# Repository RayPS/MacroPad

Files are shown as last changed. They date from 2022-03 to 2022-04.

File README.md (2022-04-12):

<h3 align="center">⌘</h3>
<h1 align="center">MacroPad</h1>
<p align="center">Yet another MacroPad but remotely configurable/scriptable/executable over Wi-Fi.<br>Most importantly, it uses much cheaper solutions than the other existing ones.</p>
<h4 align="center">🚧</h4>

# Hardware

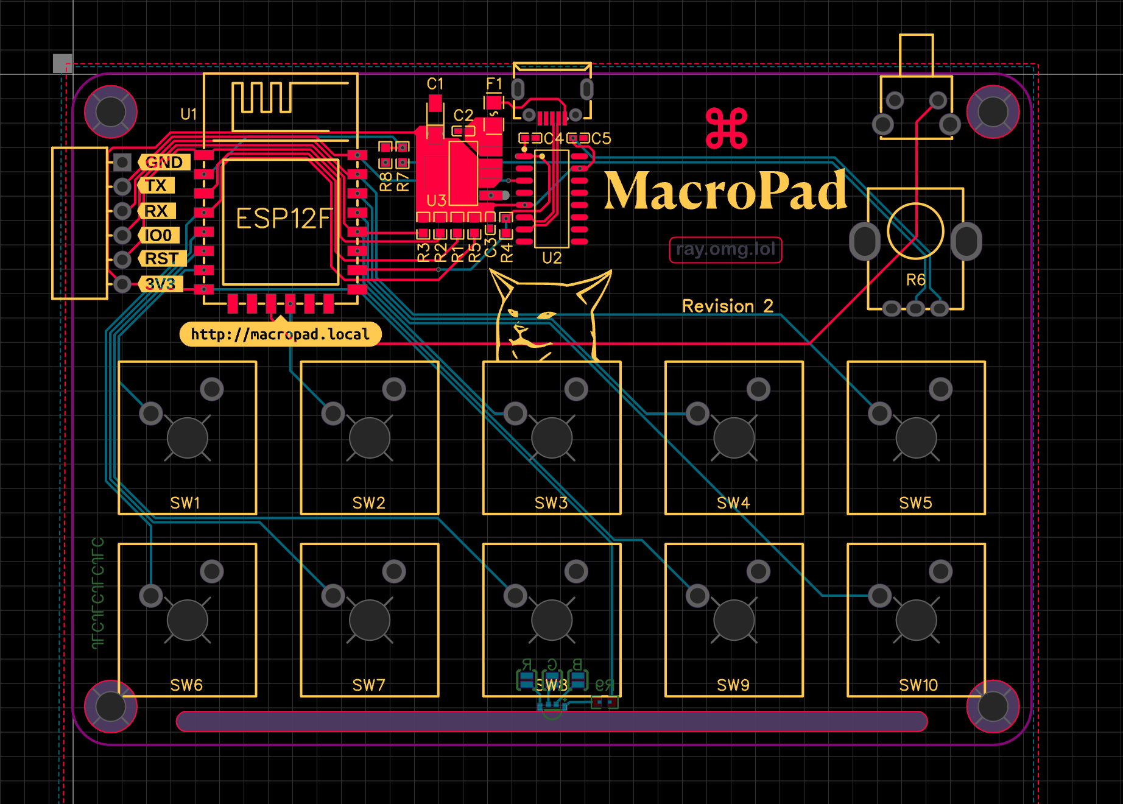
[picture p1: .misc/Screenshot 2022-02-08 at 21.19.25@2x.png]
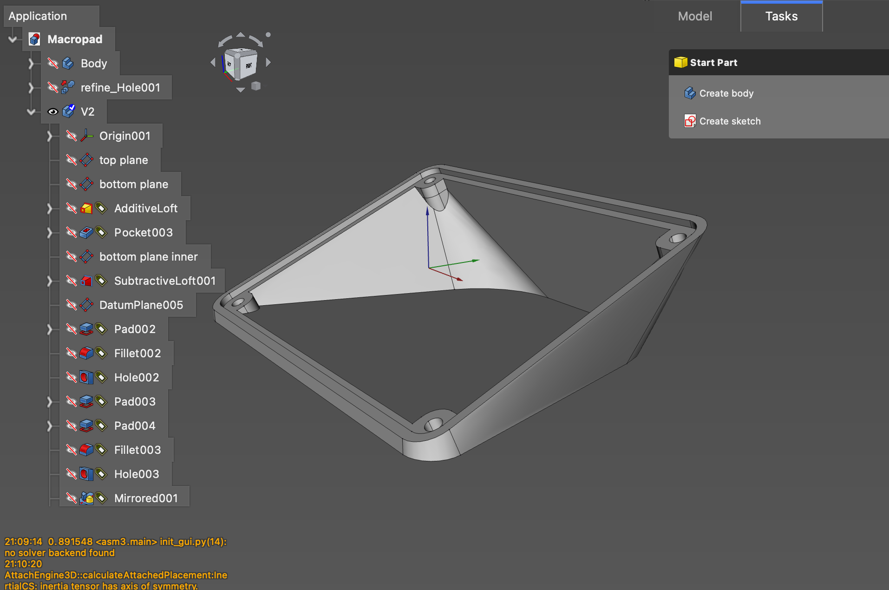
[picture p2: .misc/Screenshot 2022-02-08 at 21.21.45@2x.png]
|  |  |
| - | - |
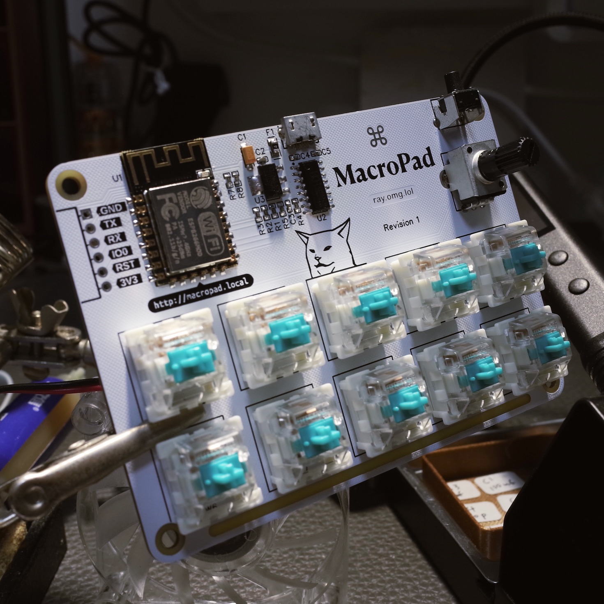
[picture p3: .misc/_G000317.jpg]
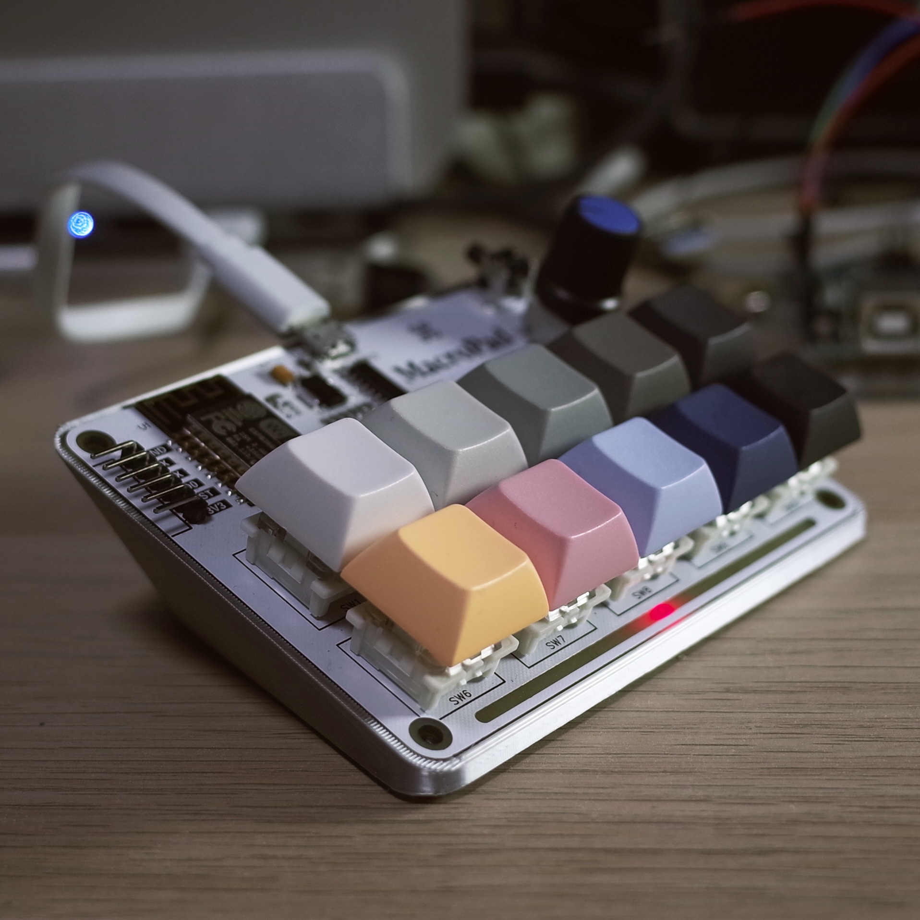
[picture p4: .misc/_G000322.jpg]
|  |  | 

### PCB

- [Exported EasyEDA Project](hardware/EasyEDA)

- [Schematic (PDF)](hardware/Schematic_MacroPad_2022-03-30.pdf)

- [Manufacturing Files (Gerber)](hardware/Gerber)

- [BOM (CSV)](hardware/BOM_MacroPad_2022-03-30.csv)

### 3D Printing Parts

There's 2 parts you can print
- Body: The stand or case whatever you call it, shown in the picture above.
- Spacer: To align the keys while soldering. This is optional.

[3D Printing Parts (STL/AMF/FreeCAD)](hardware/3D%20Prints)

It's recommended to place 4 **Silicone Rubber Feet** with diameter of 10mm underneath the body to prevent slipping.

# Web Interface
`http://macropad.local/`

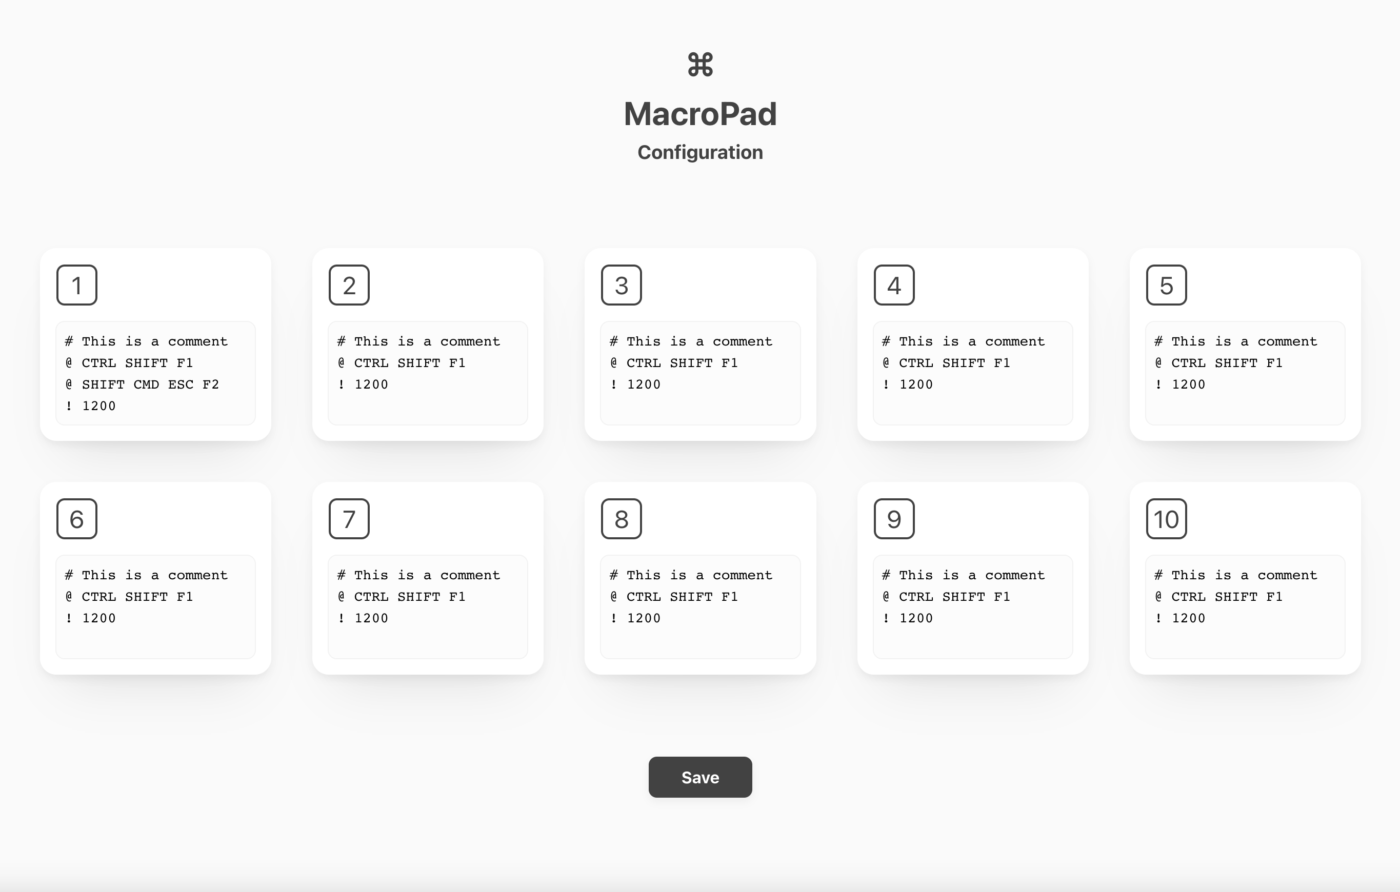
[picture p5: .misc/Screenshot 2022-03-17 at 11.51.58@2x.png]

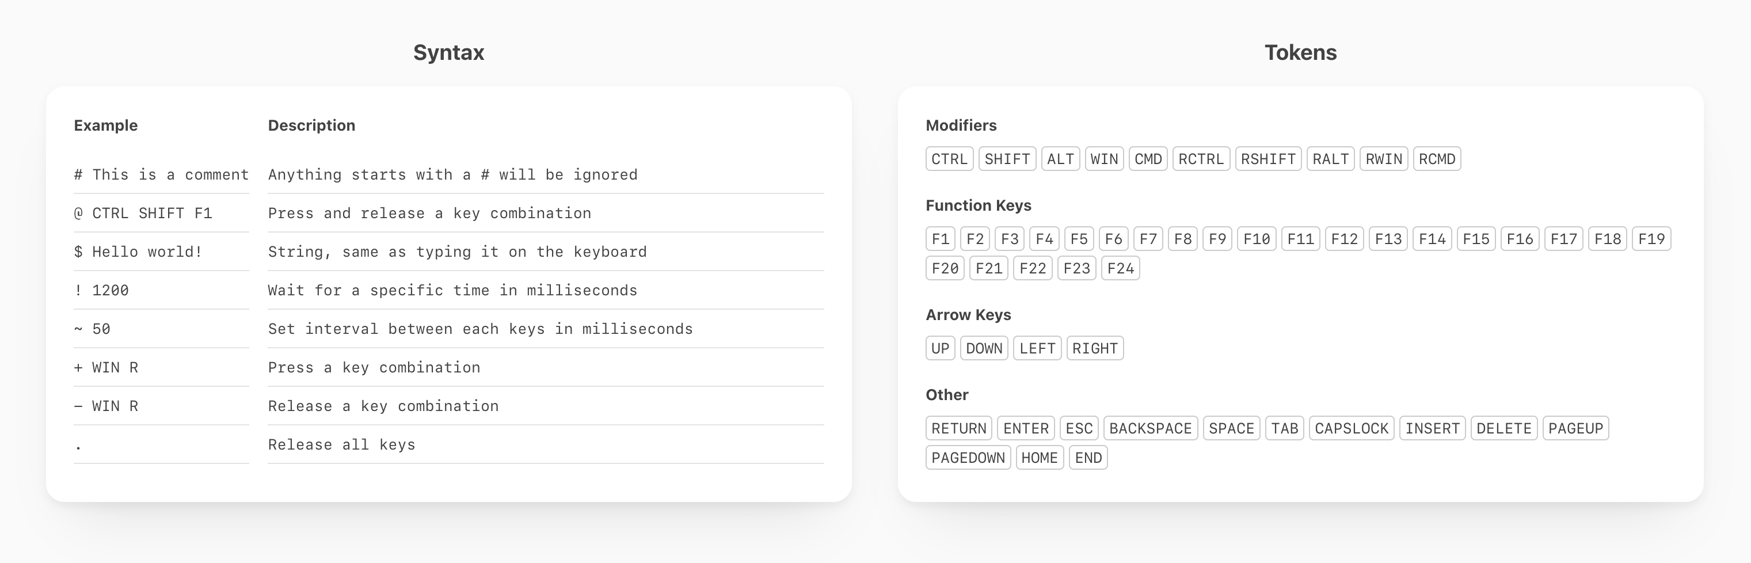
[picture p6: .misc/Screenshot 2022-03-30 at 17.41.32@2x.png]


The web interface is a Vue.js application.

See [/web](web) for more information.

# API

| **Method** | **URL** | **Description** | **Done** |
| :--- | :--- | :--- | :---: |
| `GET` | `/api/config` | read config | ✅ |
| `POST` | `/api/config` | write config | ✅ |
| `DELETE` | `/api/config` | delete config | ✅ |
| `GET` | `/api/restart` | restart | ✅ |
| `GET` | `/api/reset` | earase all settings | ✅ |

# Build / Development

> TODO: Add more information about development.

Clone this project

`git clone git@github.com:RayPS/MacroPad.git`

Open this project in PlatformIO

Update `upload_port`

Update `monitor_port` (optional, if you want to see debug messages from SoftwareSerial, otherwise remove this option)

Finally, upload to the board.

### Web Interface Development

`cd MacroPad/web`

`yarn install`

`yarn run dev` to start web development or `yarn run build` to build the html PROGMEM for the firmware.

(After `yarn run build`, you can perform an upload in PlatformIO again)

# Macro Script Proposal

<table>
    <thead>
        <tr>
            <th>Syntax</th>
            <th>Feature</th>
            <th>Done</th>
        </tr>
    </thead>
    <tbody>
        <tr>
            <td>
<pre># This is a comment
@ CTRL SHIFT CMD F1
$ Hello world!
! 1200
~ 50
+ WIN R
- WIN R
.</pre>
            </td>
            <td>
<pre>comment
shortcut
string
wait (ms)
interval (ms)
press key
release key
release all keys</pre>
            </td>
            <td>
<pre>✅
✅
✅
✅
❌
✅
✅
✅</pre>
            </td>
        </tr>
    </tbody>
</table>

# Todo
- Hardware
    - PCB
        - [ ] Use USB-C instead of Micro USB 😅
    - 3D Prints
        - [ ] Design the top case
        - [ ] Printable potentiometer cap, maybe
- Software
    - Firmware
        - [ ] Decide the functionality for the potentiometer
        - [ ] Fix the SW0 (IO9) crash
        - [ ] Implementation of ~Interval, don't see any use case yet
    - Web Interface
        - [x] Add a "usage/reference" page
        - [ ] Syntax highlighting. is this necessary?
        - [x] Config saving guard (macro syntax validation)

Features Roadmap:
- Remote execution (Already done but wont add to current version)
- Multi-configs

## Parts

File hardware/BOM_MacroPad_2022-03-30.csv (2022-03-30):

ID | Name | Designator | Footprint | Quantity | Manufacturer Part | Manufacturer | Supplier | Supplier Part | Price
1 | JUMPER-PAD-2-NOYES_SILK | B,G,R | PAD-JUMPER-2-NO_YES_SILK | 3
2 | 6x6x8 | BTN1 | SW-TH_TC-1102N-C-C-B | 1 | TC-1102N-C-C-B | XKB Enterprise | LCSC | C406158 | 0.3978
3 | 100uF | C1 | CAP-SMD_L3.2-W1.6-R-RD | 1 | T490A107M006ATE800 | KEMET | LCSC | C122251 | 1.4662
4 | 10uF | C2,C3 | C0402 | 2 | CL05A106MP5NUNC | Samsung Electro-Mechanics | LCSC | C315248 | 0.0747
5 | 200pF | C4 | C0402 | 1
6 | 100nF | C5 | C0402 | 1
7 | 0.5A | F1 | F0805 | 1 | SMD0805B050TF | Brightking Elec (TAIWAN) | LCSC | C269104 | 0.1544
8 | Program | H1 | HDR-TH_6P-P2.54-H-F-W5.7 | 1 | FFH25402-S06B1001K6K | TXGA(特思嘉) | LCSC | C2833720 | 1.1065
9 | PZ254V-11-01P | H2 | HDR-TH_1P-P2.54-V-M | 1 | PZ254V-11-01P | XFCN | LCSC | C492400 | 0.043
10 | MHS110CRGBCT | LED1 | LED-ARRAY-SMD_4P-L3.00-W1.50-R-RD | 1 | MHS110CRGBCT | MEIHUA | LCSC | C397052 | 0.744
11 | 10k | R1,R2,R3,R4,R5 | R0603 | 5
12 | 0~10K | R6 | RV0932 | 1 | RK09K1130D79 | ALPSALPINE(阿尔卑斯阿尔派) | LCSC | C2687329 | 2.51
13 | 220k | R7 | R0603 | 1
14 | 100k | R8 | R0603 | 1
15 | 100 | R9 | R0603 | 1
16 | CPG151101D93 | SW1,SW2,SW3,SW4,SW5,SW6,SW7,SW8,SW9,SW10 | SW-TH_CPG151101D9X | 10 | CPG151101D93 | Kailh(凯华) | LCSC | C400237 | 1.8695
17 | ESP-12F(ESP8266MOD) | U1 | WIFIM-SMD_ESP-12F-ESP8266MOD | 1 | ESP-12F(ESP8266MOD) | Ai-Thinker | LCSC | C82891 | 10.56
18 | CH9328 | U2 | SOP-16_L10.0-W3.9-P1.27-LS6.0-BL | 1 | CH9328 | WCH | LCSC | C82452 | 8.47
19 | AMS1117-3.3V | U3 | SOT-223-3_L6.7-W3.7-P2.30-LS7.0-BR | 1 | AMS1117-3.3 | JSMSEMI | LCSC | C917183 | 0.7379
20 | MICRO 4P DIP | USB1 | MINI-USB-SMD_MICRO-4P-DIP | 1 | MICRO 4P DIP | SHOU HAN | LCSC | C456008 | 0.2135

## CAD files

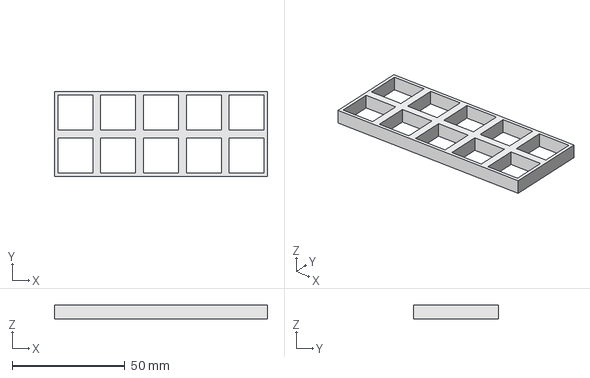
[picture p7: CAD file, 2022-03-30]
hardware/3D Prints/MacroPad-Spacer.FCStd
94.5 x 37.5 x 6.00 mm

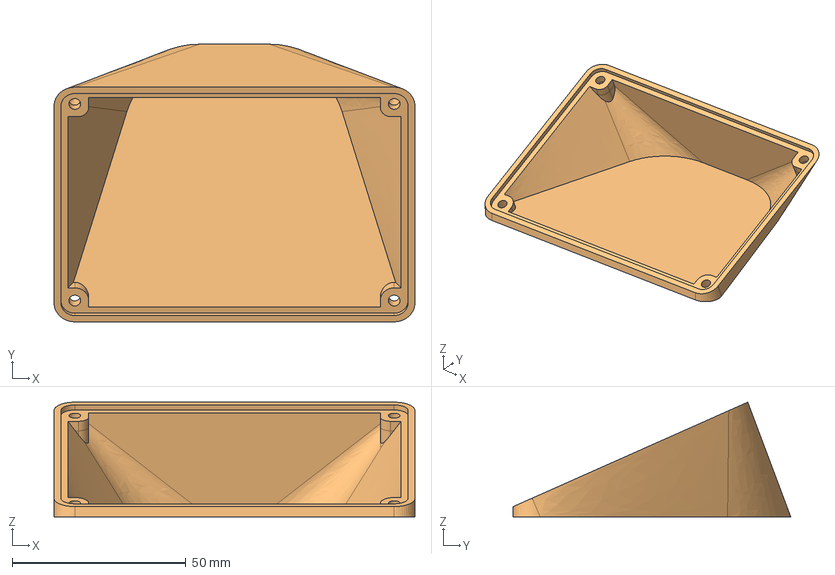
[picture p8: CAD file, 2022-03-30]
hardware/3D Prints/MacroPad.FCStd
104.0 x 80.0 x 33.0 mm
refine_Hole004

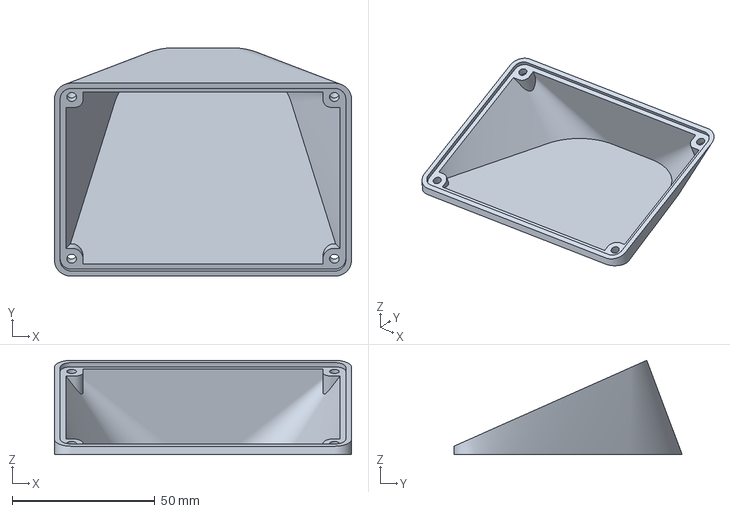
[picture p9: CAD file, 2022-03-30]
hardware/3D Prints/MacroPad (Meshed).amf
104.0 x 80.0 x 33.0 mm

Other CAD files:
hardware/3D Prints/MacroPad-Spacer-Body.stl

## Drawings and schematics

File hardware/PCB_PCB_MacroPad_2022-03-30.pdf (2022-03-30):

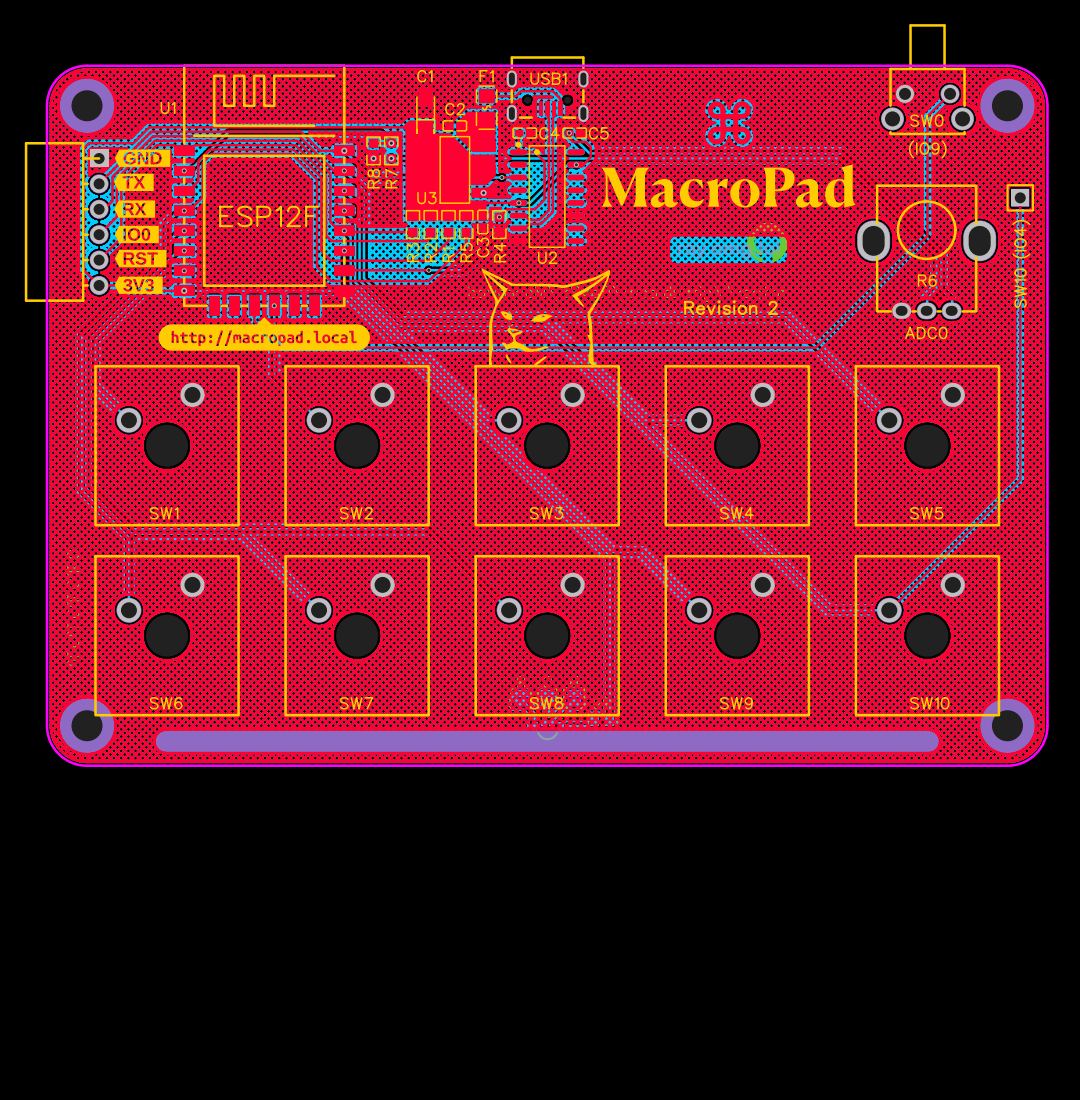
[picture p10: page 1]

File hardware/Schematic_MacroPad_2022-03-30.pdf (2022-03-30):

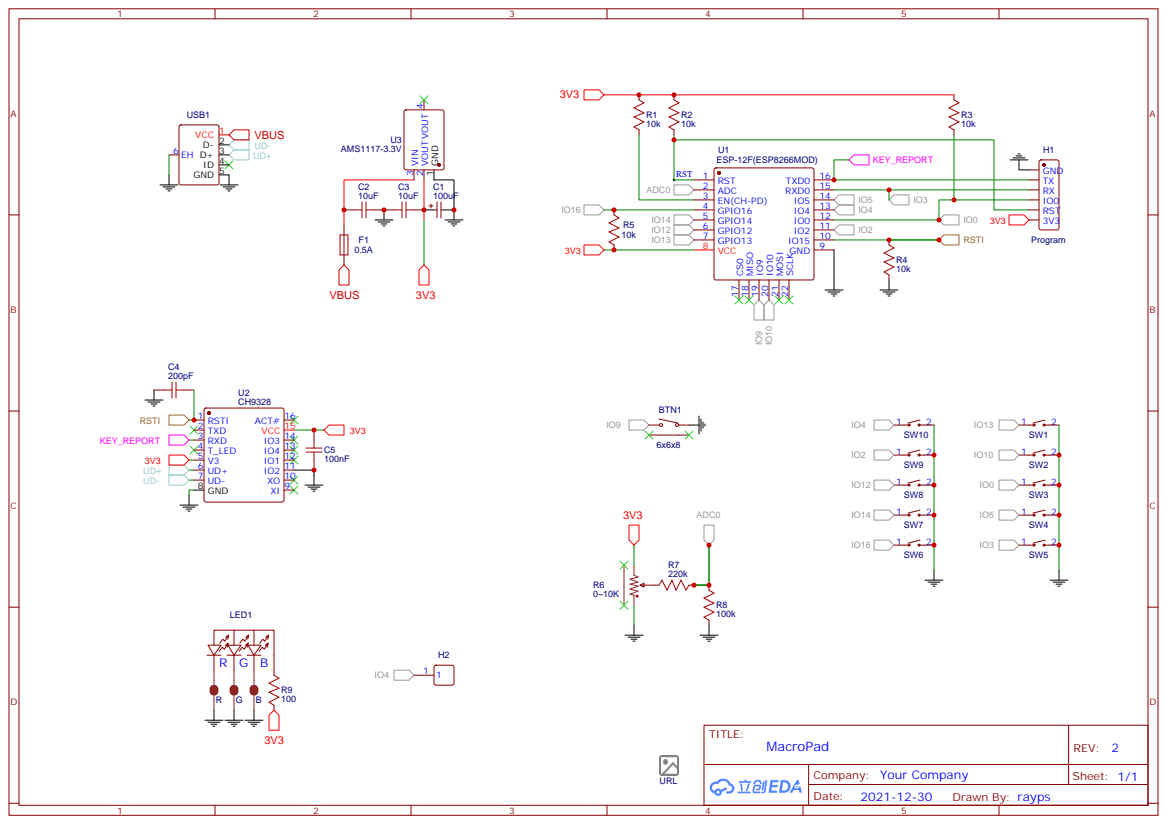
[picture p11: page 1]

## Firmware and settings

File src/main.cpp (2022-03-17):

#include <Arduino.h>

#include "utils.h"
#include "interfaceController.h"
#include "macroController.h"

void setup() {
  if (!PRODUCTION) {
    swSerial.begin(115200, SWSERIAL_8N1, -1, SWS_TX, false, 256);
    swSerial.enableIntTx(false);
    delay(50);
    swSerial.print(PSTR("\n-------- SoftwareSerial Initialized --------\n"));    
  }

  if (interfaceController.setup()) {
    macroController.setup();
    swSerial.println(PSTR("\nFinished Setup\n"));
  } else {
    swSerial.println(PSTR("\nFailed to begin\n"));
  }
}

void loop() {
  // ESP.wdtDisable(); // Fix for IO9, try remove this after finish
  interfaceController.update();
  macroController.update();
}

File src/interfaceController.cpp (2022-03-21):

#include "AsyncJson.h"
#include "ArduinoJson.h"

#include "interfaceController.h"
#include "macroController.h"
#include "utils.h"
#include "html.h"

bool InterfaceController::setup()
{
  if (!PRODUCTION) {
    DefaultHeaders::Instance().addHeader("Access-Control-Allow-Origin", "*");
    DefaultHeaders::Instance().addHeader("Access-Control-Allow-Headers", "*");
    DefaultHeaders::Instance().addHeader("Access-Control-Allow-Methods", "*");
  }

  wm.setSaveConfigCallback([](void) {
    swSerial.println(PSTR("saving config & restart"));
    ESP.restart();
  });

  if (wm.autoConnect("Macropad")) {
    swSerial.println(PSTR("Connected! IP address: ") + WiFi.localIP().toString());
    if (MDNS.begin(PSTR("macropad"))) {
      swSerial.println(PSTR("MDNS responder started: http://macropad.local/"));
      MDNS.addService( "http", "tcp", 80 );
      if(LittleFS.begin()) {
        swSerial.println(PSTR("LittleFS mounted"));
        bindAll();
        server.begin();
        return true;
      } else {
        swSerial.println(PSTR("An Error has occurred while mounting LittleFS"));
      }
    } else {
      swSerial.println(PSTR("MDNS responder failed!"));
    }
  } else {
    swSerial.println(PSTR("Failed to connect to WiFi"));
  }
  return false;
}

void InterfaceController::update()
{
  MDNS.update();
  wm.loop();
}

void InterfaceController::bindAll()
{
  server.on(PSTR("/"), HTTP_GET, [](AsyncWebServerRequest *request) {
    AsyncWebServerResponse *response = request->beginResponse_P(200, PSTR("text/html"), html, html_len);
    response->addHeader(PSTR("Content-Encoding"), PSTR("gzip"));
    request->send(response);    
  });

  server.on(PSTR("/api/restart"), HTTP_GET, [](AsyncWebServerRequest *request) {
    request->send(200, PSTR("text/plain"), PSTR("Restart"));
    ESP.restart();
  });

  server.on(PSTR("/api/reset"), HTTP_GET, [](AsyncWebServerRequest *request) {
    request->send(200, PSTR("text/plain"), PSTR("Reset"));
    ESP.reset();
  });

  server.on(PSTR("/api/config"), HTTP_DELETE, [](AsyncWebServerRequest *request) {
    LittleFS.remove("/config.json");
    request->send(200, PSTR("text/plain"), PSTR("Deleted /config.json"));
  });

  server.on(PSTR("/api/config"), HTTP_GET, [](AsyncWebServerRequest *request) {
    File configFIle = LittleFS.open("/config.json", "r");
    if (configFIle) {
      request->send(200, PSTR("application/json"), configFIle.readString());
    } else {
      request->send(500, PSTR("text/plain"), PSTR("Failed to open config file"));
    }
  });

  AsyncCallbackJsonWebHandler* setConfigHandler = new AsyncCallbackJsonWebHandler("/api/config", [](AsyncWebServerRequest *request, JsonVariant &json) {
    if (request->contentLength() > 1024) {
      request->send(400, PSTR("text/plain"), PSTR("Config too large"));
      return;
    }
    File configFile = LittleFS.open("/config.json", "w");
    serializeJson(json, configFile);
    configFile.close();
    json.clear();
    macroController.loadConfig();
    request->send(200, PSTR("text/plain"), PSTR("OK"));
  });

  server.addHandler(setConfigHandler);
}

InterfaceController interfaceController;

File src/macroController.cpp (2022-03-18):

#include "utils.h"
#include "macroController.h"

void MacroController::setup ()
{
  for (size_t i = 0; i < KEY_COUNT; i++) {
    if (!PRODUCTION && pins[i] == SWS_TX) continue;
    throttles[i].attach(pins[i], INPUT_PULLUP);
  }
  loadConfig();

  Serial.end();
  Keyboard.begin(&Serial, CH9328_RST, 9600);
  Keyboard.releaseAll();

  utils.defineTokens();
}

void MacroController::loadConfig ()
{
  swSerial.println(F("Loading /config.json..."));
  File configFile = LittleFS.open("/config.json", "r");
  config.clear();
  DeserializationError error = deserializeJson(config, configFile);
  configFile.close();
  config.garbageCollect();
  if (error) {
    swSerial.print(F("deserializeJson() failed, reason: "));
    swSerial.println(error.f_str());
    return;
  }
  if (config.overflowed()) {
    swSerial.println(PSTR("Config too large, overflowed"));
    return;
  }
  swSerial.println(PSTR("deserializeJson() Success:"));
  swSerial.println(PSTR("Config has been updated: "));
  swSerial.println("");
  swSerial.println(PSTR("Free block size: "));
  swSerial.println(ESP.getMaxFreeBlockSize());
  swSerial.println("");
  serializeJsonPretty(config, swSerial);
}

void MacroController::update ()
{
  for (size_t i = 0; i < KEY_COUNT; i++) {
    if (!PRODUCTION && pins[i] == SWS_TX) continue;
    throttles[i].update();
    if (throttles[i].fell()) {
      if (config.size() != 0) {
        JsonArrayConst macro = config["macros"].getElement(i);
        if (!macro.isNull()) {
          swSerial.println("Key " + (String) i + " fell with macro:");
          serializeJsonPretty(macro, swSerial);
          swSerial.println("");
          runMacro(macro);
        } else {
          swSerial.println("Key " + (String) i + " fell but config failed to load");
          swSerial.println(F("config: "));
          serializeJsonPretty(config, swSerial);
          swSerial.println("");
          swSerial.println(F("config[macros]: "));
          serializeJsonPretty(config["macros"], swSerial);
          swSerial.println("");
        }
      } else {
        swSerial.println("Key " + (String) i + " fell wihout config");
      }
    }
  }
}

int MacroController::parseShortcut (char shortcut[], int result[MACRO_KEY_COUNT_MAX])
{
  char *token;
  const char *delimiter = " ";
  int count = -1;

  token = strtok(shortcut, delimiter);

  while (token != NULL) {
    String tokenString = token;
    tokenString.trim();
    tokenString.toUpperCase();
    if (count > -1) { // Skip '@'
      if (utils.tokens.containsKey(tokenString)) {
        result[count] = utils.tokens[tokenString].as<int>();
      } else {
        result[count] = tolower(token[0]);
      }
    }
    token = strtok(NULL, delimiter);
    count++;
  }
  
  return count;
}

void MacroController::sendShortcut (int keys[MACRO_KEY_COUNT_MAX], int keyCount, bool press)
{
  for (int i = 0; i < keyCount; i++) {
    if (press) {
      swSerial.print("press key: ");
      swSerial.println(String(keys[i]));
      Keyboard.press(keys[i]);
    } else {
      swSerial.print("release key: ");
      swSerial.println(String(keys[i]));
      Keyboard.release(keys[i]);
    }
  }
}

void MacroController::runMacro (JsonArrayConst macro)
{
  for (String line : macro) {
    line.trim();
    if (line.length() == 0) continue;

    char lineBuf[MACRO_LINE_MAX];
    line.toCharArray(lineBuf, MACRO_LINE_MAX);

    switch (lineBuf[0])
    {
    case '#': // Comment
      swSerial.println(PSTR("\nComment, skipped"));
      break;
    case '@': // Shortcut
      {
        swSerial.println(PSTR("\nShortcut"));
        int keys[MACRO_KEY_COUNT_MAX];
        int keyCount = parseShortcut(lineBuf, keys);
        sendShortcut(keys, keyCount, true);
        sendShortcut(keys, keyCount, false);
      }
      break;
    case '$': // String
      swSerial.println(PSTR("\nString"));
      line.remove(0, 2);
      Keyboard.print(line);
      break;
    case '+': // Press
      {
        swSerial.println(PSTR("\nPress"));
        int keys[MACRO_KEY_COUNT_MAX];
        int keyCount = parseShortcut(lineBuf, keys);
        sendShortcut(keys, keyCount, true);
      }
      break;
    case '-': // Release
      {
        swSerial.println(PSTR("\nRelease"));
        int keys[MACRO_KEY_COUNT_MAX];
        int keyCount = parseShortcut(lineBuf, keys);
        sendShortcut(keys, keyCount, false);
      }
      break;
    case '.': // Release All
      swSerial.println(PSTR("\nRelease All"));
      Keyboard.releaseAll();
      break;
    case '~': // Set interval ms
      swSerial.println(PSTR("\nSet interval ms"));
      break;
    case '!': // Wait ms
      swSerial.println(PSTR("\nWait ms"));
      swSerial.println(atoi(lineBuf + 1));
      delay(atoi(lineBuf + 1));
      break;
    default:
      swSerial.println(PSTR("\nUnknown command"));
      break;
    }
  }
}

MacroController macroController;

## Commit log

2022-03-22 Add Button component
2022-03-30 Add hardware files
    [BOM_MacroPad_2022-03-30.csv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]
2022-03-30 Update BOM csv format
    [BOM_MacroPad_2022-03-30.csv]
